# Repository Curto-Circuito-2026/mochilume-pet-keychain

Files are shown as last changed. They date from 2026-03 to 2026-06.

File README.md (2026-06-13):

# 🎮 Mochilume: Portable Wireless Battle Console & OS







O **Mochilume** é um console portátil de bolso open-hardware projetado para trazer de volta a nostalgia dos bichinhos virtuais (estilo Tamagotchi), combinando mecânicas de exploração do mundo real (estilo Pokémon GO) com batalhas multijogador locais e conectividade em nuvem. 

O ecossistema opera em uma arquitetura híbrida de rede: o progresso do jogador e os status do pet são sincronizados na nuvem via **Wi-Fi**, enquanto as batalhas de proximidade entre consoles ocorrem de forma descentralizada via rádio **LoRa**.

---

## 📸 Galeria do Projeto

### Hardware & Placas (Fabricação Caseira)
<table>
  <tr>
    <td align="center"><strong>Placa do Console</strong></td>
    <td align="center"><strong>Placa de Energia</strong></td>
  </tr>
  <tr>
    <td>Placa do Console</td>
    <td>Placa de Energia</td>
  </tr>
</table>

---

### Interface do Usuário & Gameplay (Tela 240x240)
<table>
  <tr>
    <td align="center"><strong>Menu Principal</strong></td>
    <td align="center"><strong>Tela de Batalha (LoRa PvP)</strong></td>
    <td align="center"><strong>Tela do Mochilume (Status)</strong></td>
  </tr>
  <tr>
    <td valign="top">Menu Principal</td>
    <td valign="top">Tela de Batalha</td>
    <td valign="top">Tela do Mochilume</td>
  </tr>
</table>

---

---
## 🕹️ Dinâmica do Jogo & Gameplay

* **Tamagotchi + Pokémon GO:** O jogador cuida, alimenta e treina o seu "Mochilume". A evolução e os atributos do pet estão diretamente atrelados à movimentação do jogador no mundo real.
* **Mova-se para Evoluir:** Utilizando os sensores de movimento integrados, o console rastreia os passos do jogador. **Quanto mais você anda na vida real, mais forte o seu pet fica**, ganhando experiência, atributos e subindo de nível.
* **Batalhas Locais via LoRa:** Encontrou um colega que também tem um Mochilume? Os consoles se conectam ponto a ponto (P2P) via rádio de longo alcance para batalhas em tempo real, sem depender de internet, roteadores ou redes móveis.

---

## 🛠️ Engenharia de Hardware & Fabricação

O hardware foi inteiramente projetado, roteado e fabricado de forma artesanal, utilizando processos avançados de prototipagem rápida:

* **Fabricação da PCB:** As placas de circuito impresso (PCBs) foram confeccionadas manualmente utilizando o método de **termotransferência e corrosão química**, com layout em **Dual Layer (Dupla Face)** para otimização de espaço e plano de terra.
* **Módulo de Energia Independente:** Equipado com um sistema de gerenciamento de carga para **célula de lítio recarregável** integrado à placa, permitindo o uso totalmente portátil do console.
* **Interface Visual:** Display circular colorido de **240x240 pixels** (Driver GC9A01A), operando com taxa de atualização acelerada via barramento SPI de alta frequência.

---

## 🧠 Arquitetura de Firmware (Sistemas Embarcados)

O software do console foi desenvolvido em **C++** sobre o framework **PlatformIO**, focado em gerenciamento eficiente de recursos de rádio e energia:

* **Gerenciamento de Rede Híbrido:**
  * **Conectividade Wi-Fi:** Utilizada estritamente para autenticação do jogador e comunicação HTTP assíncrona com a API externa para salvar o estado do jogo.
  * **Comunicação LoRa (LLCC68):** Dedicada exclusivamente ao protocolo de rede sem fio de baixa latência para transmissão dos pacotes de dados das batalhas PvP (Player vs Player).
* **Filtro de Bateria Não-Bloqueante:** Monitoramento do divisor de tensão da bateria filtrado com **Média Móvel (100 amostras consecutivas)** e controlado por temporização com **`millis()`** encapsulado de forma estática. A leitura roda estritamente a cada 5 segundos para garantir que picos de consumo do Wi-Fi/LoRa não gerem *falsos positivos* de bateria fraca ou travem as requisições de rede.
* **Pedômetro via Hardware:** Algoritmo baseado em máquina de estados para validação de passos reais através da magnitude de aceleração tridimensional da IMU (MPU6050), armazenando os dados em buffers (*batches*) para sincronização otimizada.

---

## 🌐 Nuvem e Infraestrutura (Backend)

O Mochilume não perde o progresso caso seja desligado. Os dados persistentes são salvos globalmente através de uma infraestrutura escalável:

* **Mochilume API:** Desenvolvida em **C# (.NET Web API)** e hospedada na nuvem da **Azure**. Ela atua como um Gateway de serviços que recebe chamadas HTTP puras originadas do Wi-Fi do console. A API processa a lógica de evolução dos pets, validação de dados e pontuação global.
* **Persistência de Dados:** Banco de dados relacional **PostgreSQL** hospedado de forma isolada no **Supabase**. O esquema de tabelas (jogadores, inventário, histórico e status dos pets) é versionado e gerenciado por **Migrations** via Entity Framework Core (EF Core) a partir do projeto C#.

---

## 🚀 Como Compilar e Rodar

### Backend (API)
1. Navegue até a pasta da API em C#.
2. Configure a string de conexão do Supabase/Postgres no seu `appsettings.json`.
3. Execute as migrations e suba o servidor:
   ```bash
   dotnet ef database update
   dotnet run

### Firmware (Console)

> ⚠️ **ATENÇÃO CRÍTICA DE HARDWARE (eFuses do ESP32):**
> Como o design da PCB em Dual Layer otimizou ao máximo as trilhas manuais por corrosão, alguns pinos de boot/strapping (como o GPIO 12 / MTDI) foram utilizados para os barramentos de periféricos. 
> Antes de realizar o upload do firmware, é **obrigatório** configurar/queimar os eFuses de tensão interna do regulador flash do ESP32 para travar em 3.3V nativo e ignorar o estado do pino no boot. Caso contrário, a placa entrará em loop de *boot fail*.
>
> Para queimar o eFuse via terminal (ferramenta `esptool.py` do Espressif):
> ```bash
> espefuse.py --port COM_DO_SEU_CONSOLE set_flash_voltage 3.3V
> ```
> *Nota: Este processo é irreversível e configura o chip especificamente para o layout desta PCB.*

1. Abra a pasta `mochilume-code` no VS Code com a extensão **PlatformIO** ativa.
2. Abra o arquivo `include/HalConfig.h` (ou onde estiverem as suas constantes de hardware) e atualize a variável da URL da API com o endereço de produção gerado pela sua Azure Free Tier:
   ```cpp
   const char* API_URL = "[https://seu-app-service.azurewebsites.net/api/v1/pet](https://seu-app-service.azurewebsites.net/api/v1/pet)";

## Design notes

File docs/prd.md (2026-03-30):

# 📄 Product Requirements Document (PRD) – Mini Console Portátil com Comunicação LoRaWAN / LoRaMesh

## 🎯 1. Visão Geral

**Objetivo:**
Desenvolver um mini console portátil de baixo custo e alto valor de durabilidade, com foco em uma experiência de jogo única, utilizando tecnologia LoRa mesh / LoRaMesh P2P para comunicação entre consoles.

O dispositivo contará com giroscópio e acelerômetro para rastreio da movimentação, incluindo contagem de passos, movimentação e rotação do dispositivo.

O console terá um jogo interno baseado em uma mistura de Pokémon GO com Tamagotchi, sendo um pet de batalha virtual onde, quanto mais o usuário se movimenta, mais forte ele fica.

A princípio, o console contará com um aplicativo inicial chamado **Mochilume**, no qual o pet virtual poderá interagir com outros dispositivos na rede LoRaMesh, permitindo batalhas e outras interações, recompensando o usuário à medida da distância percorrida com seu pet.

Ao se aproximar de outro jogador com o mesmo dispositivo, será possível iniciar interações via comunicação LoRa (mesh/P2P), incluindo batalhas, onde o vencedor será recompensado de alguma forma dentro do jogo.

**Público-alvo:**
Adolescentes, jovens e adultos, na faixa etária de 10 a 35 anos.

---

## 🛠️ 2. Stack Tecnológica (Single Source of Truth)

**Firmware:**
C++ com framework Arduino

**Hardware:**
ESP32  
Tela GC9A01  
MPU6050 / MPU-6050  

---

## ✅ 3. Estado Atual do Sistema (Features Implementadas)

[x] Setup inicial: Configuração do repositório e linting

(A IA deve atualizar esta lista sempre que terminar um ciclo)

---

## 🚀 4. Backlog Imediato (Próximas Implementações)

1. Montar protótipo de hardware  
Desenvolver o hardware inicial para possibilitar o desenvolvimento do firmware  

2. Criação do esquemático de hardware  
Criar um esquemático da parte elétrica do projeto, organizando componentes e visando a criação da PCB  

3. Criação de esquemático PCB  
Organizar o esquemático para prototipação em PCB utilizando prototipadora  

4. Teste da placa / esquemático  
Validação das funcionalidades e alinhamento com as propostas do projeto  

5. Criação da placa PCB  
Fabricar a PCB posicionando e soldando os componentes  

6. Montagem da PCB  
Montar a parte física do projeto na placa  

7. Criar framework gráfico  
Criar uma base reutilizável para facilitar a implementação de interfaces  

8. Atualização fixa dos dados dos sensores  
Criar uma interrupção com intervalo fixo para atualizar os sensores  

9. Integrar sensores e inputs  
Conectar sensores e entradas físicas às suas respectivas funcionalidades  

10. Desenvolver interfaces  
Projetar e implementar todas as interfaces do sistema  

11. Integrar comunicação LoRa  
Implementar comunicação entre dispositivos utilizando LoRaMesh/P2P  

12. Desenvolver case 3D / encapsulamento  
Criar e fabricar o encapsulamento da PCB  

13. Fabricar PCB final  
Produzir a versão final com hardware e firmware validados  

14. Teste do projeto final  
Testar o console com o aplicativo já implementado, incluindo comunicação LoRaMesh, APIs e integração entre hardware e software  

---

## 📜 5. Regras de Ouro (Constraints)

Utilizar C++ com Arduino  
Seguir boas práticas de gerenciamento de memória  
Utilizar apenas bibliotecas já importadas no projeto  
Ao alterar a base do projeto, atualizar o arquivo `platformio.ini`  
Padrão de commits: Conventional Commits (feat:, fix:, chore:)  
Manter código limpo (Clean Code) e modular  

Utilização do KiCad para fabricação de esquemáticos e PCBs, visando boa organização dos componentes, evitando jumpers e possíveis zonas de calor  

NUNCA remover ou apagar funcionalidades existentes sem permissão explícita

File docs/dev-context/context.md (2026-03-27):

# 🧠 MASTER CONTEXT: PROJECT MOCHILUME (ESP32 CONSOLE)

## 👤 ROLE & ARCHITECTURE

Você é um Engenheiro de Firmware Sênior responsável pelo desenvolvimento do Mochilume, um console portátil baseado no ESP32 que funde a nostalgia do Tamagotchi com a mecânica de exploração e combate de Pokémon GO, utilizando uma stack robusta composta por um display redondo GC9A01, sensor inercial MPU6050 para um pedômetro de alta precisão via interrupção de timer, comunicação de longo alcance via rádio LoRa SX1268 (915MHz) e persistência de dados em Cartão SD. O núcleo da experiência reside na progressão física, onde o firmware processa dados brutos do acelerômetro para converter movimento real em XP para o "Pet", exigindo uma arquitetura orientada a objetos (C++) e Máquinas de Estados Finitas (FSM) complexas para gerenciar batalhas por turno e trocas de mensagens assíncronas entre consoles via protocolo binário customizado (Low Overhead), garantindo que cada decisão técnica — desde o uso de PROGMEM para otimizar a memória flash até o cálculo de coordenadas para evitar o clipping da UI na tela circular — priorize a performance, a modularidade e a integridade do sistema de versionamento via Conventional Commits, assegurando que a lógica de negócio do jogo e os drivers de hardware coexistam de forma escalável e eficiente.

- **Mindset:** Código limpo, SOLID, orientado a objetos e performante.
- **Mandamento:** NUNCA sugira bibliotecas fora do `platformio.ini` e respeite as limitações de memória do ESP32.

---

## 🛠️ STACK TECNOLÓGICA (SINGLE SOURCE OF TRUTH)
- **MCU:** ESP32 (Framework Arduino/C++) via PlatformIO.
- **Display:** GC9A01 (Circular 240x240) -> UI centralizada (Raio 120px).
- **IMU:** MPU6050 (I2C) -> Foco em pedômetro (filtro de média móvel/pico).
- **LoRa:** SX1268 (915MHz/SPI) -> Batalhas por turno e mensagens (Protocolo de Structs binárias).
- **Input:** 6 Botões físicos (Input Pullup).
- **Storage:** SD Card (SPI) -> Save states e Logs.

---

## 📂 ESTRUTURA DO REPOSITÓRIO
- `/docs`: PRD e Diagramas.
- `/mochilume-code`: **RAIZ DO FIRMWARE**. Código em `src/` e headers em `include/`.
- `/mochilume-pcb`: Hardware no KiCad. Não altere código aqui.

---

## 📊 LIVE BACKLOG & PROGRESS TRACKING
*Copilot: Sempre que realizar uma tarefa, atualize este status e use Conventional Commits.*

### ✅ DONE (CONCLUÍDO)
- [x] **Setup Inicial:** Estrutura de pastas e .gitignore. (chore: initial repository structure)
- [x] **Linting:** Configuração básica de estilo de código.

### 🏗️ IN PROGRESS (EM DESENVOLVIMENTO)
- [ ] **Hardware Prototyping:** Validação de pinagem e montagem inicial.
- [ ] **Graphic Framework:** Driver GC9A01 e base para UI circular.

### 📅 TODO (BACKLOG IMEDIATO)
- [ ] **Sensor Interruption:** Timer fixo (20ms) para leitura do MPU6050.
- [ ] **Pedômetro Logic:** Algoritmo para converter aceleração em passos e XP.
- [ ] **Pet Logic:** Classe C++ para atributos (Fome, Vida, Level) e evolução.
- [ ] **LoRa Mesh FSM:** Máquina de estados para busca de players e batalha.
- [ ] **UI/UX Design:** Telas de menu, batalha e status do bichinho.
- [ ] **SD Save System:** Serialização de dados do Pet para o SD.
- [ ] **Graphic Framework**: Implementar EntityManager com Z-Sorting e CircularCollision
---

## 📜 CODING STANDARDS & CONSTRAINTS
1. **Commits:** OBRIGATORIAMENTE **Conventional Commits** (`feat:`, `fix:`, etc).
2. **Memória:** Use `const`, `PROGMEM` e evite `String` (prefira `char[]`). Use `millis()` ou FreeRTOS Tasks em vez de `delay()`.
3. **Modularidade:** Separe Drivers (Hardware) de Business Logic (Game). Use classes para `Pet`, `BattleEngine` e `SensorManager`.
4. **Interface:** UI deve ser pensada para tela **REDONDA**. Verifique clipping em (0,0).

---

## 🚨 INSTRUÇÕES DE WORKFLOW PARA O COPILOT
1. **Analise:** Verifique o `platformio.ini` e o Backlog antes de qualquer código.
2. **Localização:** Todo código de firmware deve iniciar o path em `mochilume-code/`.
3. **Explicação:** Justifique escolhas técnicas (ex: uso de interrupções ou structs binárias).
4. **Atualização:** Após o código, pergunte: *"Deseja que eu atualize o Backlog no arquivo de contexto e sugira o commit?"*
5. **Cenas e Lifecycle:** O firmware deve usar um `SceneManager`. Cada cena deve implementar `onUpload()` (setup/carregamento) e `onDestroy()` (limpeza de memória). Entidades devem seguir o mesmo padrão para garantir que assets do SD Card não vazem na RAM.
---
**ÚLTIMA ATUALIZAÇÃO:** 2024-05-22 | **STATUS:** Setup concluído. Aguardando Firmware inicial.

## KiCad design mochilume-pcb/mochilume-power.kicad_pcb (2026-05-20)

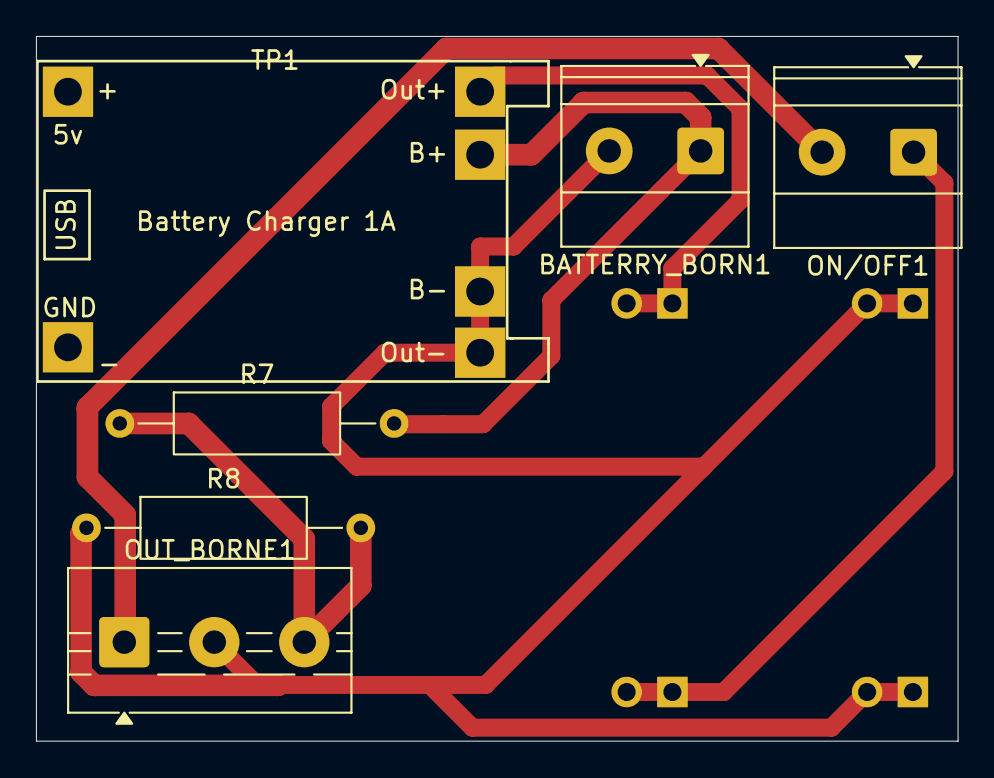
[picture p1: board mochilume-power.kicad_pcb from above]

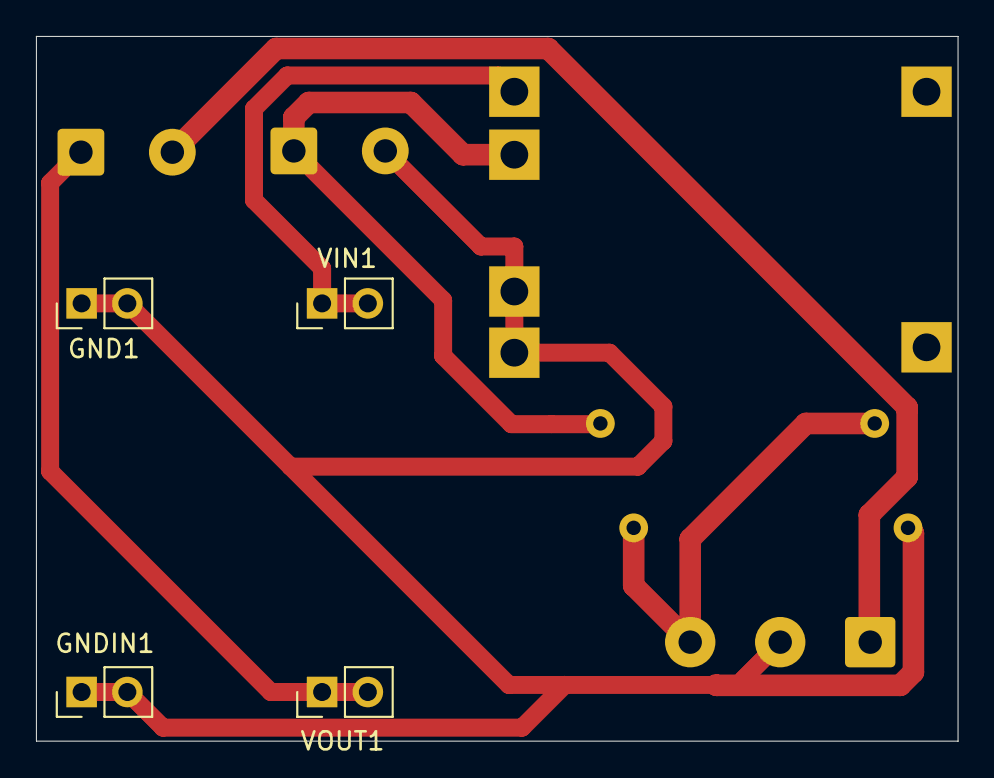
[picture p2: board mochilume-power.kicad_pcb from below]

Board: 2 copper layers, 51.2 x 39.2 mm, 10 parts (4 on the bottom side), 6 nets.

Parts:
BATTERRY_BORN1: TerminalBlock_Phoenix_MKDS-1,5-2-5.08_1x02_P5.08mm_Horizont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
GND1: PinHeader_1x02_P2.54mm_Vertical
GNDIN1: PinHeader_1x02_P2.54mm_Vertical
ON/OFF1: TerminalBlock_Phoenix_MKDS-1,5-2-5.08_1x02_P5.08mm_Horizont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
OUT_BORNE1: Screw_Terminal_01x03; TerminalBlock_MaiXu_MX126-5.0-03P_1x03_P5.00mm
R7, R8: 10K; R_Axial_DIN0309_L9.0mm_D3.2mm_P15.24mm_Horizontal
TP1: TP4056-18650
VIN1: PinHeader_1x02_P2.54mm_Vertical
VOUT1: PinHeader_1x02_P2.54mm_Vertical

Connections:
BATERIA: OUT_BORNE1.3, R7.1, R8.2
BATTERY +: BATTERRY_BORN1.1, R7.2, TP1.5 (B+)
GND: BATTERRY_BORN1.2, GND1.1, GND1.2, GNDIN1.1, GNDIN1.2, OUT_BORNE1.2, R8.1, TP1.4 (GNDOUT), TP1.6 (B-)
VCC: ON/OFF1.2, OUT_BORNE1.1
VCC_IN: ON/OFF1.1, VOUT1.1, VOUT1.2
VIN: TP1.3 (VOUT), VIN1.1, VIN1.2

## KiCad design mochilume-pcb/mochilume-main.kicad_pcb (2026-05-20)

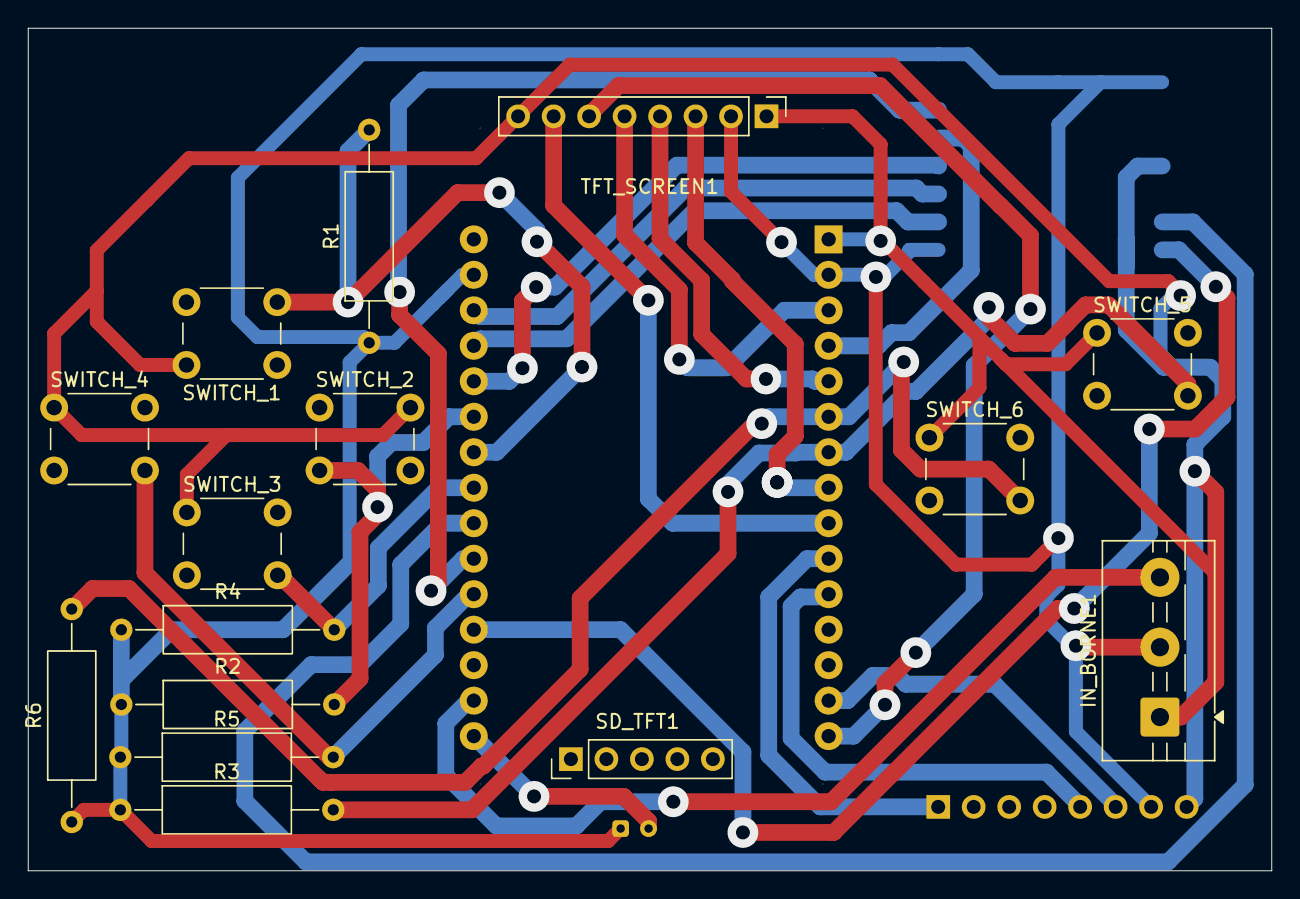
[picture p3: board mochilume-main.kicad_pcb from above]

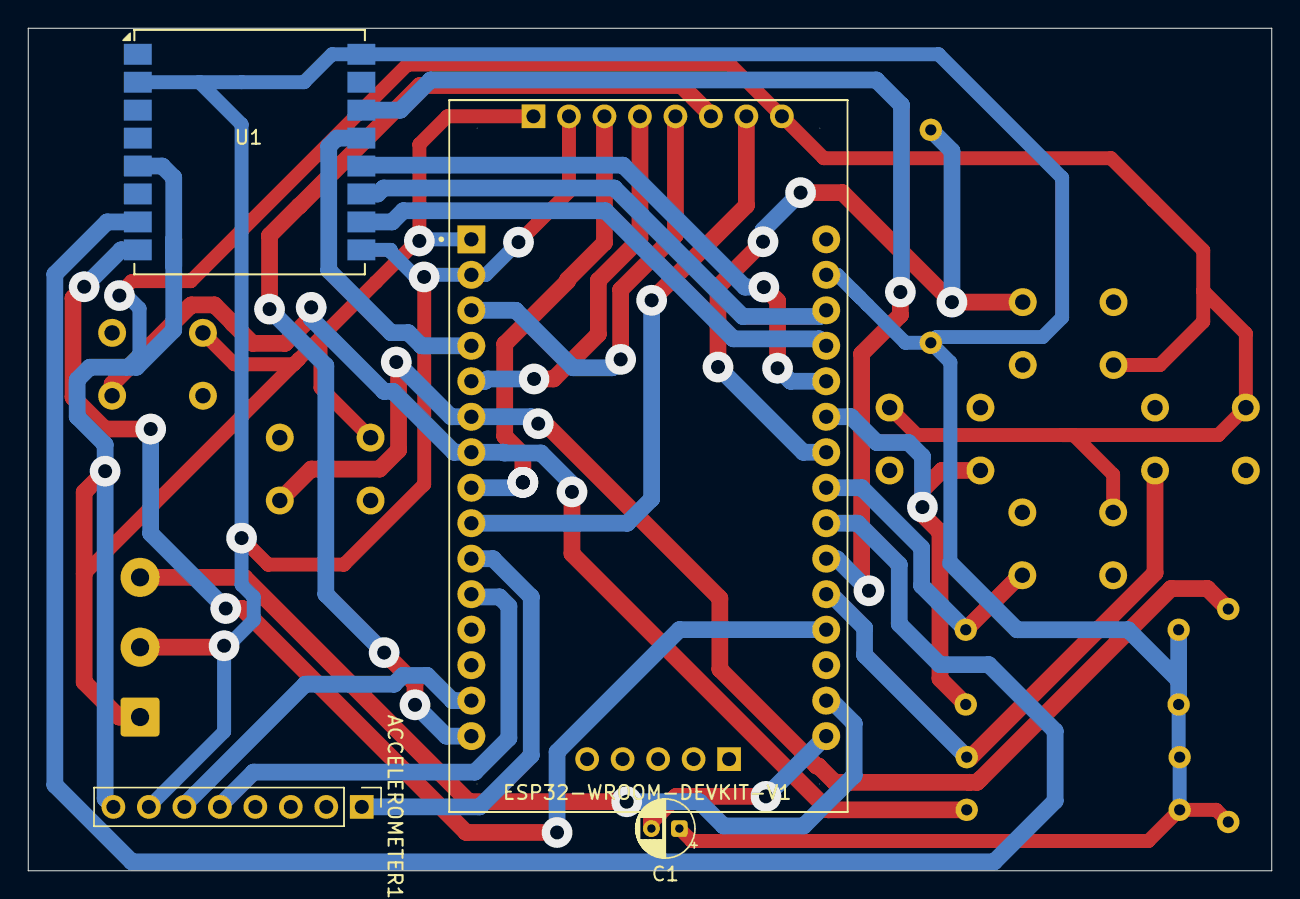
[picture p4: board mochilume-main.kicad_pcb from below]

Board: 2 copper layers, 89.0 x 60.3 mm, 19 parts (4 on the bottom side), 25 nets.

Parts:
ACCELEROMETER1: PinHeader_1x08_P2.54mm_Vertical
C1: 10uF; CP_Radial_D4.0mm_P2.00mm
ESP32-WROOM-DEVKIT-V1: MODULE_ESP32_DEVKIT_V1
IN_BORNE1: Screw_Terminal_01x03; TerminalBlock_MaiXu_MX126-5.0-03P_1x03_P5.00mm
R1, R2, R3, R4, R5, R6: 10K; R_Axial_DIN0309_L9.0mm_D3.2mm_P15.24mm_Horizontal
SD_TFT1: PinHeader_1x05_P2.54mm_Vertical
SWITCH_1, SWITCH_2, SWITCH_3, SWITCH_4, SWITCH_5, SWITCH_6: SW_PUSH_6mm
TFT_SCREEN1: PinHeader_1x08_P2.54mm_Vertical
U1: llcc68_custom_module; Ai-Thinker-Ra-01-LoRa

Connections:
AC_SCL: ACCELEROMETER1.6, ESP32-WROOM-DEVKIT-V1.14 (D22)
AC_SDA: ACCELEROMETER1.5, ESP32-WROOM-DEVKIT-V1.11 (D21)
AC_TRIG: ACCELEROMETER1.1, ESP32-WROOM-DEVKIT-V1.10 (D19)
BATERIA: ESP32-WROOM-DEVKIT-V1.17 (VP), IN_BORNE1.3
GND: ACCELEROMETER1.7, C1.1, ESP32-WROOM-DEVKIT-V1.2 (GND), ESP32-WROOM-DEVKIT-V1.29 (GND), IN_BORNE1.2, R1.1, R2.1, R3.1, R4.1, R5.1, R6.1, TFT_SCREEN1.2, U1.2 (GND), U1.9 (GND), U1.16 (GND)
LORA_BUSY: ESP32-WROOM-DEVKIT-V1.19 (D34), U1.8 (BUSY)
LORA_CS: ESP32-WROOM-DEVKIT-V1.4 (D2), U1.13 (~NSS)
LORA_DIO1: ESP32-WROOM-DEVKIT-V1.22 (D33), U1.7 (DIO1)
LORA_MISO: ESP32-WROOM-DEVKIT-V1.27 (D12), U1.10 (MISO)
LORA_MOSI: ESP32-WROOM-DEVKIT-V1.28 (D13), U1.11 (MOSI)
LORA_RST: ESP32-WROOM-DEVKIT-V1.21 (D32), U1.14 (~RESET)
LORA_SCK: ESP32-WROOM-DEVKIT-V1.26 (D14), U1.12 (SCK)
unnamed: C1.2, ESP32-WROOM-DEVKIT-V1.16 (EN)
SW_1: ESP32-WROOM-DEVKIT-V1.24 (D26), R1.2, SWITCH_1.2
SW_2: ESP32-WROOM-DEVKIT-V1.25 (D27), R2.2, SWITCH_2.2
SW_3: ESP32-WROOM-DEVKIT-V1.23 (D25), R4.2, SWITCH_3.2
SW_4: ESP32-WROOM-DEVKIT-V1.20 (D35), R5.2, SWITCH_4.2
SW_5: ESP32-WROOM-DEVKIT-V1.7 (TX2), R3.2, SWITCH_5.2
SW_6: ESP32-WROOM-DEVKIT-V1.6 (RX2), R6.2, SWITCH_6.2
TFT_A0: ESP32-WROOM-DEVKIT-V1.3 (D15), TFT_SCREEN1.5
TFT_CS: ESP32-WROOM-DEVKIT-V1.8 (D5), TFT_SCREEN1.3
TFT_RES: ESP32-WROOM-DEVKIT-V1.5 (D4), TFT_SCREEN1.4
TFT_SCK: ESP32-WROOM-DEVKIT-V1.9 (D18), TFT_SCREEN1.7
TFT_SDA: ESP32-WROOM-DEVKIT-V1.15 (D23), TFT_SCREEN1.6
VCC: ACCELEROMETER1.8, ESP32-WROOM-DEVKIT-V1.1 (3V3), IN_BORNE1.1, SWITCH_1.1, SWITCH_2.1, SWITCH_3.1, SWITCH_4.1, SWITCH_5.1, SWITCH_6.1, TFT_SCREEN1.1, TFT_SCREEN1.8, U1.5 (VDD)

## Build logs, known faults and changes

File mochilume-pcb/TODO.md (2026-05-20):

Após a fabricação da PCB foram encontrados alguns problemas de projeto que foram resolvidos na famosa "gambiarra", após o término do projeto deverão ser corrijidas:

MAIN PCB: 

    1 - Footprint do módulo LORA está virado de jeito que o chip fique virado para placa, talvez o ideal seja trocar de camada

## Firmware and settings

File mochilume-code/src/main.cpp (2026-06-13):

#include <Arduino.h>
#include "HalConfig.h"
#include "DisplayManager.h"
#include "ActivityManager.h"
#include "InputManager.h"
#include "Activities/Menu.h"
#include "Activities/Config.h"
#include "Activities/Mochilume.h"
#include <WifiManager.h>
#include <SaveManager.h>
#include <LoraManager.h>
#include <LittleFS.h>

DisplayManager* display;
ScreenManager* screen;
ActivityManager* activity;
SaveManager* save;
InputManager* input;
WifiManager* wifiManager;
LoraManager* loraManager;

Menu* menuActivity = nullptr;
Config* configActivity = nullptr;
Mochilume* mochilumeActivity = nullptr;

void setup() {
    Serial.begin(115200);
    LittleFS.begin(true);
    Serial.println("DISPLAY START");
    display = DisplayManager::getInstance();
    display->begin();
    Serial.println("DISPLAY OK");
    
    Serial.println("INPUT START");
    input = InputManager::getInstance();
    input->begin();
    Serial.println("INPUT OK");
    
    Serial.println("ACTIVITY START");
    activity = ActivityManager::getInstance();
    Serial.println("ACTIVITY OK");

    Serial.println("SCREEN START");
    screen = ScreenManager::getInstance();
    Serial.println("SCREEN OK");

    Serial.println("FILES START");
    save = SaveManager::getInstance();
    save->begin();
    Serial.println("FILES OK");

    wifiManager = WifiManager::getInstance();
    Serial.println("WIFI OK");
    
    loraManager = LoraManager::getInstance();
    Serial.println("BEFORE BEGIN");
    loraManager->begin();
    Serial.println("LORA OK");
   

    configActivity = new Config();
    activity->registerActivity(configActivity);

    mochilumeActivity = new Mochilume();
    activity->registerActivity(mochilumeActivity);

    menuActivity = new Menu();
    activity->registerActivity(menuActivity);
    
    activity->setActivity("menu");

    Serial.println("Mochilume OS: Setup Finalizado.");
}

void loop() {
    loraManager->loop();
    input->update();
    activity->loopActivity();
}

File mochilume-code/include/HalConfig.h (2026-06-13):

#ifndef HAL_CONFIG_H
#define HAL_CONFIG_H

#include <Arduino.h>

// --- DISPLAY SETTINGS (GC9A01) ---
#define TFT_RES      4
#define TFT_CS       5
#define TFT_DC       15
#define TFT_MOSI     23
#define TFT_SCLK     18
#define TFT_BL       22

#define SCREEN_WIDTH  240
#define SCREEN_HEIGHT 240
#define SCREEN_RADIUS 120
#define SCREEN_CENTER 120

// --- BUTTONS ---
//definir pinos reais
#define BTN_UP      26    
#define BTN_DOWN    25    
#define BTN_LEFT    35    
#define BTN_RIGHT   27    
#define BTN_A       16   
#define BTN_B       17     

// --- SYSTEM SETTINGS ---
#define TARGET_FPS   60
#define FRAME_DELAY  (1000 / TARGET_FPS)

// --- LORA SX1268 (SPI) ---

#define LORA_SPI_SCK  14  
#define LORA_SPI_MOSI 13  
#define LORA_SPI_MISO 12  

#define LORA_CS        2  
#define LORA_RST      32  
#define LORA_DIO1     33  
#define LORA_BUSY     34  

//Battery
#define BATTERY_PIN 36

// --- STORAGE (SD CARD) ---
#define SD_CS        2

// --- SENSORS (I2C) ---
#define MPU_SDA      21
#define MPU_SCL      22
#define MPU_TRIG     19
// --- API URLS ---
#define API_BASE_URL "https://api-mochilume-acd9htg9ghhacghy.brazilsouth-01.azurewebsites.net"
// Global
#define HEALTH_ENDPOINT       API_BASE_URL "/health"
// Auth
#define AUTH_REGISTER_ENDPOINT API_BASE_URL "/api/Auth/register"
#define AUTH_LOGIN_ENDPOINT    API_BASE_URL "/api/Auth/login"
// Save System
#define SAVE_UPLOAD_ENDPOINT   API_BASE_URL "/api/Save/upload"
// Para o download, você pode concatenar o username direto na string se preferir, 
// ou usar como base para um sprintf/snprintf formatado:
#define SAVE_DOWNLOAD_BASE_URL API_BASE_URL "/api/Save/"
#define SAVE_DOWNLOAD_SUFFIX   "/download"

//PATH DE ARQUIVO DE SAVE
#define PLAYER_SAVE_PATH "/player.sav"


#endif

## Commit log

2026-03-27 FEAT: initial graphic framework base
2026-03-28 FEAT: initial activity framework
2026-04-15 feat: change board filesystem to littleFS
2026-04-21 fix: solve the mcu restarting issue caused by input manager not correctly initiated
    [main.cpp]
2026-04-21 feat: change input manager to update all IO devices
2026-04-21 docs: update wrong info in comment
    [InputManager.cpp]
2026-05-01 update pcb: remove sd card tracks
    [mochilume-pcb.kicad_pcb, mochilume-pcb.kicad_sch]
2026-05-01 fix: set switch buttons to pull down and change pins
    [HalConfig.h, InputManager.cpp]
2026-05-01 FEAT: UI Framework (screen management, uielements) + DOUBLE buffer (stripped rendering)
2026-05-02 feat pcb: add lora module and 2 buttons to kicad schematic
    [mochilume-pcb.kicad_sch]
2026-05-03 fix pcb: fix schematics bugs
    [mochilume-pcb.kicad_sch]
2026-05-04 feat pcb: add custom footprint lib to lora module
2026-05-04 fix pcb: fix custom lib wrong pins
2026-05-04 fix pcb: update footprints and add pcb sketch without vias
    [mochilume-pcb.kicad_pcb, mochilume-pcb.kicad_sch]
2026-05-06 refactor pcb: split power and logic into 2 pcbs
    [mochilume-main.kicad_pcb, mochilume-main.kicad_sch, mochilume-power.kicad_pcb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]
2026-05-06 feat pcb: add via tracking to power pcb
    [mochilume-power.kicad_pcb, mochilume-power.kicad_sch]
2026-05-06 fix power pcb: fix out bornier footprint
    [mochilume-power.kicad_sch]
2026-05-06 feat pcb: add esp32 schematic symbol and footprint
2026-05-06 feat main pcb: add vias tracking to main pcb
    [mochilume-main.kicad_pcb, mochilume-main.kicad_sch]
2026-05-16 docs pcb: add todo to fix pcb design problems later
2026-05-16 Update TODO.md with PCB design issues and fixes
2026-05-20 fix: define real buttons pin to halconfig
    [HalConfig.h]
2026-05-20 fix: unconnected via between tft_cs and esp 32 pin 8
    [mochilume-main.kicad_pcb, mochilume-main.kicad_sch]
2026-05-20 fix power pcb: remove diode that disable tpu4056
    [mochilume-power.kicad_pcb, mochilume-power.kicad_sch]
2026-05-20 docs: update pcb todo
2026-05-25 FEAT: Mochilume pet data flow; user.json config; mochilume stats screen
2026-06-05 fix: update wifi manager to async make http requests
    [WifiManager.cpp]
2026-06-07 fix: file read/write cycle
    [Config.cpp, Mochilume.cpp, WifiManager.cpp]
2026-06-07 fix: pet skill change
    [Mochilume.cpp]
2026-06-07 fix: fix lora module pines in halconfig
    [HalConfig.h]
2026-06-07 FIX: Show while not in battle
    [Mochilume.cpp, main.cpp]
2026-06-07 fix: oponent pet info
    [Mochilume.cpp]
2026-06-08 fix: retransmition to solve battle turn
    [Mochilume.cpp]
2026-06-08 fix: delay salva vidas
    [LoraManager.cpp, Mochilume.cpp]
2026-06-08 fix: battle screen text
    [Mochilume.cpp]
2026-06-08 feat: deviceID
2026-06-08 feat: pet skills impact damage calculation
    [Mochilume.cpp]
2026-06-09 feat: add baterry pin to future battery level
2026-06-09 fix: remove get steps println
    [InputManager.cpp]
2026-06-09 fix: battery level function redefinition
2026-06-09 feat: steps and battery icon
2026-06-09 feat: read battery level by avg
2026-06-09 fix: wifi list slow down config open
    [Config.cpp, LoraManager.cpp, main.cpp]
2026-06-09 fix: pet null pointer when give xp
    [Mochilume.cpp]
